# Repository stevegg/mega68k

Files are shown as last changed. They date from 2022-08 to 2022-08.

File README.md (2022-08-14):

# Steve's Mega68k
This project was inspired by others.  It's the unholy union of an Motorola MC68000 CPU and MC68681 DUART with an Arduino Mega along with an AdaFruit SD Card breakout.  This is my attempt to bootstrap building a single board CPU with appropriate software to make it interesting.  My goals are to get the software to a point where it can run both CP/M 68k and a scaled down version of Linux.  

Right now there are 2 software projects:
- Mega68k freerun - implementing a simple freerun mode
- Mega68k simpleLopp - implementing a simple loop and using the arduino as ROM.

Both of these are in the software sub-directory.
The hardware sub-directory contains the KiKad 6.0 project along with the required symbol and footprint libraries and the gerbers.

For Arduino software development I'm using VSCode and the platformio plugin.  This provides a pleasant and smooth development experience.

For assembler I'm using Easy68k...this provides a less smooth and pleasant development experience but it does work and the simulation is quite useful.

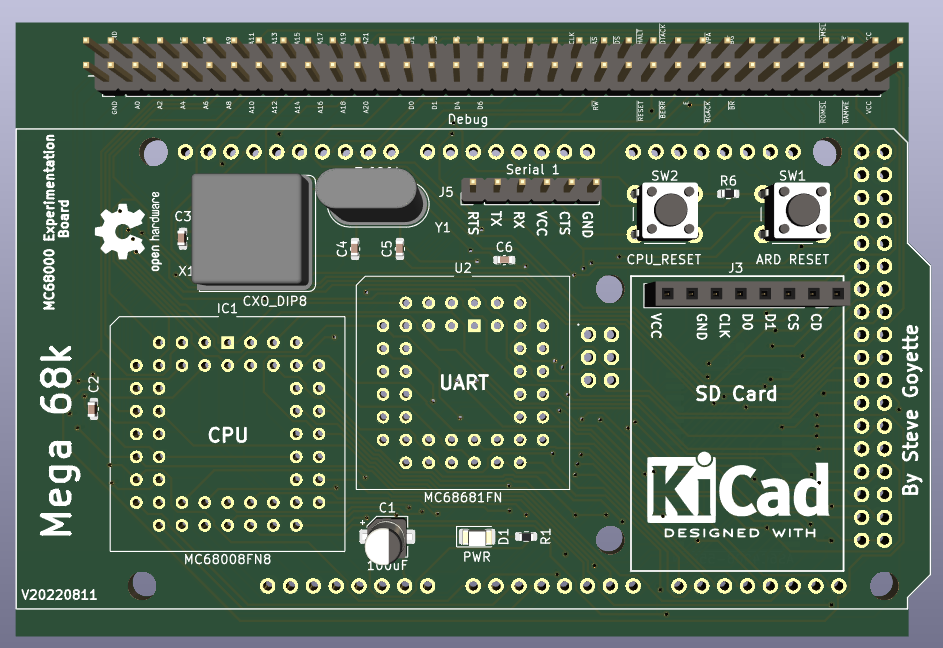
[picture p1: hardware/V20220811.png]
V20220811


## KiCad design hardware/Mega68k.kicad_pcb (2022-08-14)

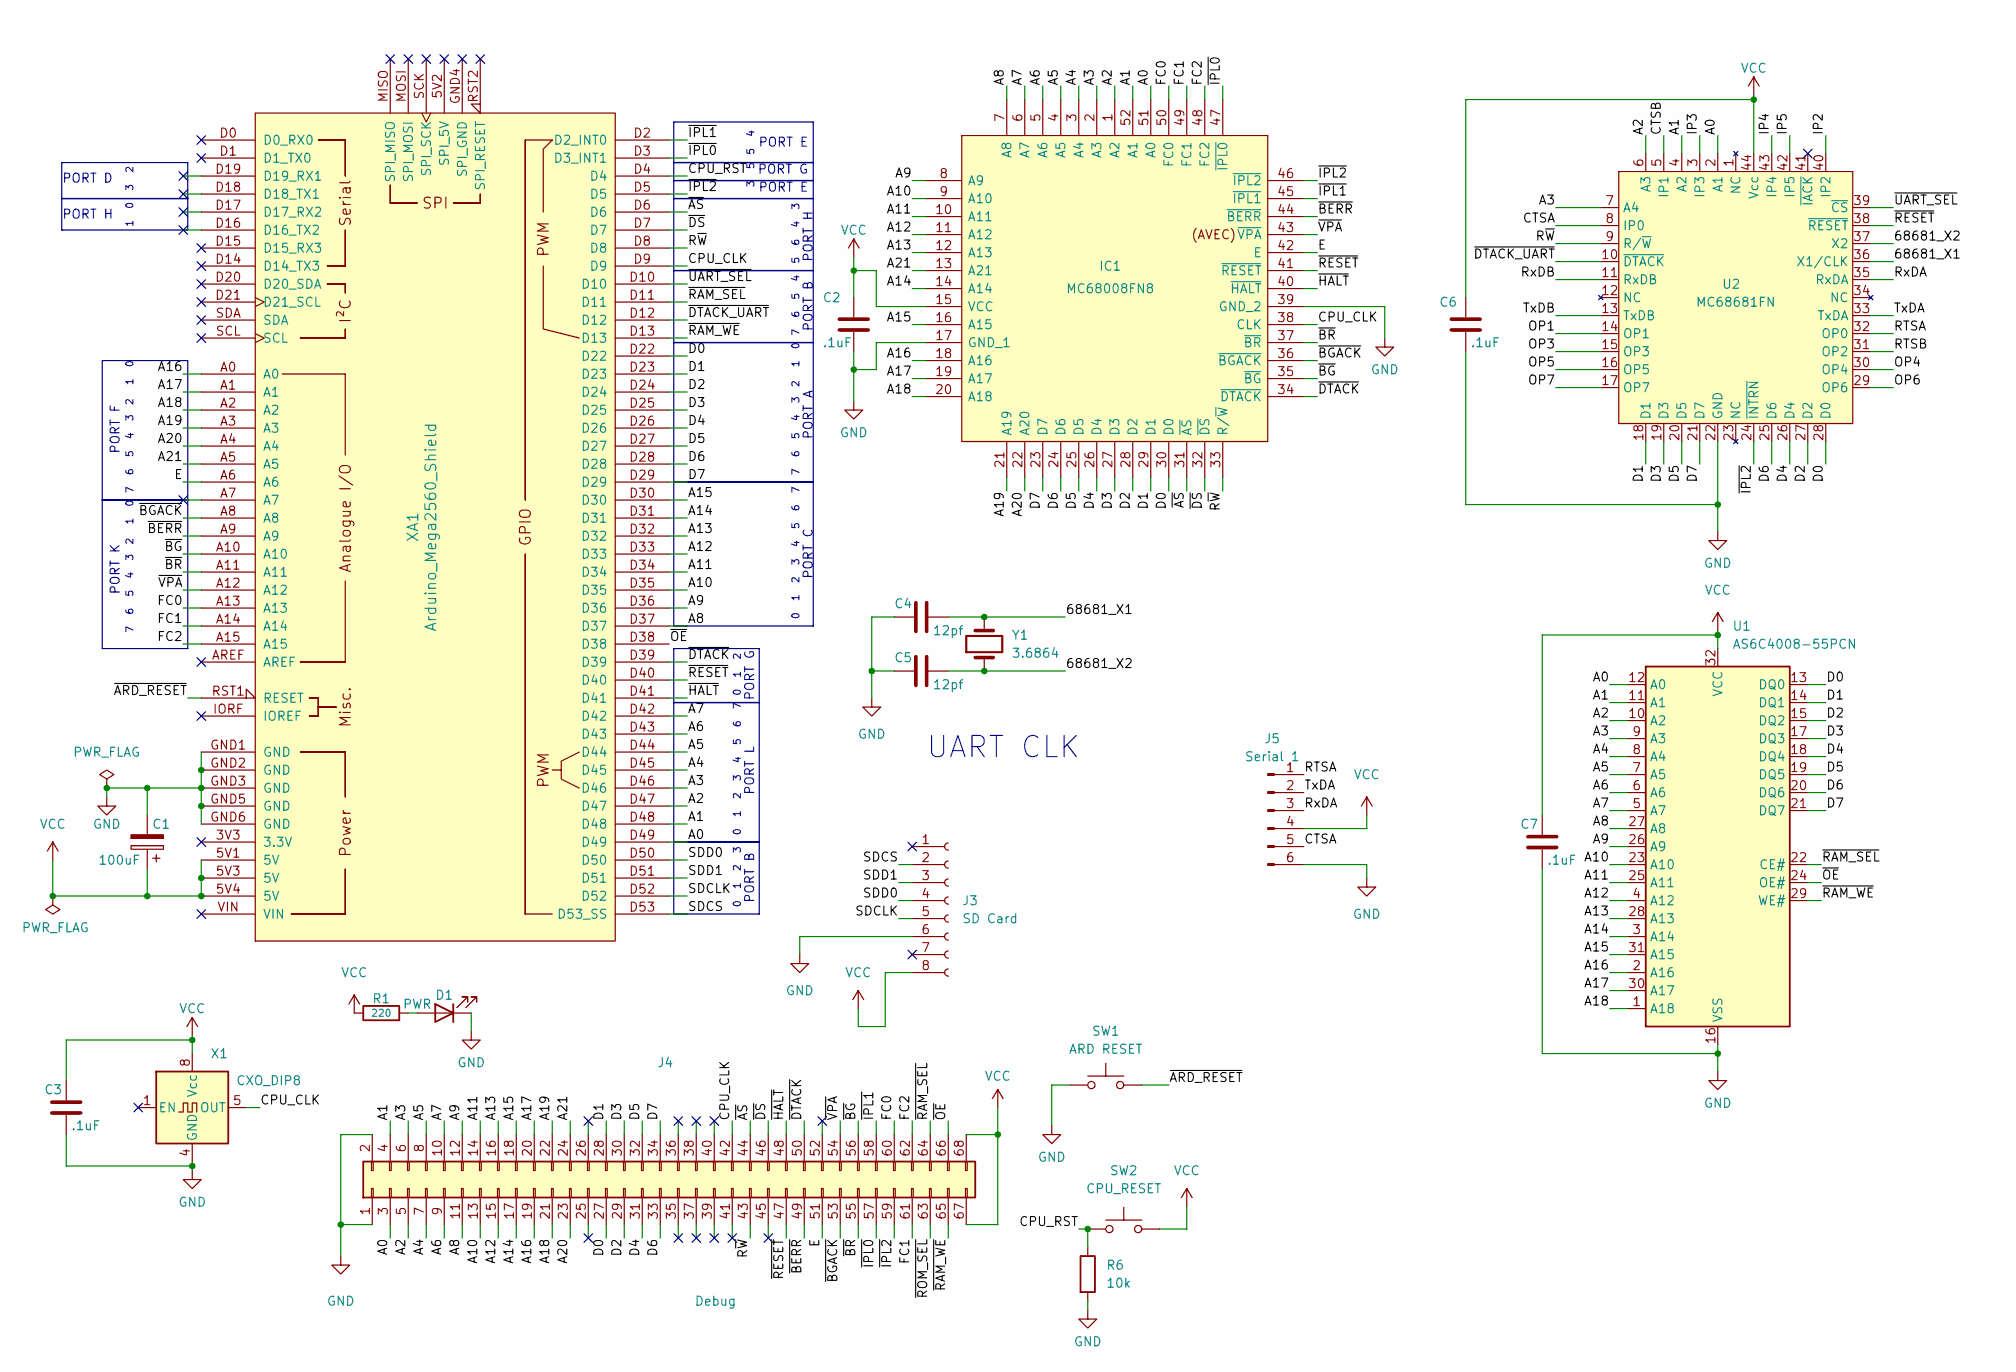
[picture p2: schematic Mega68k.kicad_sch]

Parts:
C1: 100uF; CP_Elec_4x5.4
C2, C3, C6, C7: .1uF; C_0603_1608Metric
C4, C5: 12pf; C_0603_1608Metric
D1: PWR; LED_1206_3216Metric
IC1: MC68008FN8; PLCC-52_THT-Socket; Manufacturer_Part_Number MC68008FN8
J3: SD Card; PinSocket_1x08_P2.54mm_Vertical
J4: Debug; PinHeader_2x34_P2.54mm_Vertical
J5: Serial 1; PinHeader_1x06_P2.54mm_Vertical
R1: 220; R_0603_1608Metric
R6: 10k; R_0603_1608Metric
SW1: ARD RESET; SW_PUSH_6mm
SW2: CPU_RESET; SW_PUSH_6mm
U1: AS6C4008-55PCN; SSOP-32_11.305x20.495mm_P1.27mm
U2: MC68681FN; PLCC-44_THT-Socket
X1: CXO_DIP8; Oscillator_DIP-8
XA1: Arduino_Mega2560_Shield
Y1: 3.6864; Crystal_HC49-U_Vertical

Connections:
/68681_X1: C4.2, U2.36 (X1/CLK), Y1.2
/68681_X2: C5.2, U2.37 (X2), Y1.1
/A0: IC1.51 (A0), J4.3, U1.12 (A0), U2.2 (A1), XA1.D49
/A1: IC1.52 (A1), J4.4, U1.11 (A1), U2.4 (A2), XA1.D48
/A2: IC1.1 (A2), J4.5, U1.10 (A2), U2.6 (A3), XA1.D47
/A3: IC1.2 (A3), J4.6, U1.9 (A3), U2.7 (A4), XA1.D46
/A4: IC1.3 (A4), J4.7, U1.8 (A4), XA1.D45
/A5: IC1.4 (A5), J4.8, U1.7 (A5), XA1.D44
/A6: IC1.5 (A6), J4.9, U1.6 (A6), XA1.D43
/A7: IC1.6 (A7), J4.10, U1.5 (A7), XA1.D42
/A8: IC1.7 (A8), J4.11, U1.27 (A8), XA1.D37
/A9: IC1.8 (A9), J4.12, U1.26 (A9), XA1.D36
/A10: IC1.9 (A10), J4.13, U1.23 (A10), XA1.D35
/A11: IC1.10 (A11), J4.14, U1.25 (A11), XA1.D34
/A12: IC1.11 (A12), J4.15, U1.4 (A12), XA1.D33
/A13: IC1.12 (A13), J4.16, U1.28 (A13), XA1.D32
/A14: IC1.14 (A14), J4.17, U1.3 (A14), XA1.D31
/A15: IC1.16 (A15), J4.18, U1.31 (A15), XA1.D30
/A16: IC1.18 (A16), J4.19, U1.2 (A16), XA1.A0
/A17: IC1.19 (A17), J4.20, U1.30 (A17), XA1.A1
/A18: IC1.20 (A18), J4.21, U1.1 (A18), XA1.A2
/A19: IC1.21 (A19), J4.22, XA1.A3
/A20: IC1.22 (A20), J4.23, XA1.A4
/A21: IC1.13 (A21), J4.24, XA1.A5
/CPU_CLK: IC1.38 (CLK), J4.42, X1.5 (OUT), XA1.D9
/CPU_RST: R6.1, SW2.1, XA1.D4
/CTSA: J5.5, U2.8 (IP0)
/CTSB: U2.5 (IP1)
/D0: IC1.30 (D0), J4.27, U1.13 (DQ0), U2.28 (D0), XA1.D22
/D1: IC1.29 (D1), J4.28, U1.14 (DQ1), U2.18 (D1), XA1.D23
/D2: IC1.28 (D2), J4.29, U1.15 (DQ2), U2.27 (D2), XA1.D24
/D3: IC1.27 (D3), J4.30, U1.17 (DQ3), U2.19 (D3), XA1.D25
/D4: IC1.26 (D4), J4.31, U1.18 (DQ4), U2.26 (D4), XA1.D26
/D5: IC1.25 (D5), J4.32, U1.19 (DQ5), U2.20 (D5), XA1.D27
/D6: IC1.24 (D6), J4.33, U1.20 (DQ6), U2.25 (D6), XA1.D28
/D7: IC1.23 (D7), J4.34, U1.21 (DQ7), U2.21 (D7), XA1.D29
/E: IC1.42 (E), J4.51, XA1.A6
/FC0: IC1.50 (FC0), J4.60, XA1.A13
/FC1: IC1.49 (FC1), J4.61, XA1.A14
/FC2: IC1.48 (FC2), J4.62, XA1.A15
/IP2: U2.40 (IP2)
/IP3: U2.3 (IP3)
/IP4: U2.43 (IP4)
/IP5: U2.42 (IP5)
/OP1: U2.14 (OP1)
/OP3: U2.15 (OP3)
/OP4: U2.30 (OP4)
/OP5: U2.16 (OP5)
/OP6: U2.29 (OP6)
/OP7: U2.17 (OP7)
/RTSA: J5.1, U2.32 (OP0)
/RTSB: U2.31 (OP2)
/RxDA: J5.3, U2.35 (RxDA)
/RxDB: U2.11 (RxDB)
/R~W: IC1.33 (R/~W), J4.43, U2.9 (R/~W), XA1.D8
/SDCLK: J3.5, XA1.D52
/SDCS: J3.2, XA1.D53 (D53_SS)
/SDD0: J3.4, XA1.D50
/SDD1: J3.3, XA1.D51
/TxDA: J5.2, U2.33 (TxDA)
/TxDB: U2.13 (TxDB)
/~ARD_RESET: SW1.2, XA1.RST1 (RESET)
/~AS: IC1.31 (~AS), J4.44, XA1.D6
/~BERR: IC1.44 (~BERR), J4.49, XA1.A9
/~BGACK: IC1.36 (~BGACK), J4.53, XA1.A8
/~BG: IC1.35 (~BG), J4.56, XA1.A10
/~BR: IC1.37 (~BR), J4.55, XA1.A11
/~DS: IC1.32 (~DS), J4.46, XA1.D7
/~DTACK_UART: U2.10 (~DTACK), XA1.D12
/~DTACK: IC1.34 (~DTACK), J4.50, XA1.D39
/~HALT: IC1.40 (~HALT), J4.48, XA1.D41
/~IPL0: IC1.47 (~IPL0), J4.57, XA1.D3 (D3_INT1)
/~IPL1: IC1.45 (~IPL1), J4.58, XA1.D2 (D2_INT0)
/~IPL2: IC1.46 (~IPL2), J4.59, U2.24 (~INTRN), XA1.D5
/~OE: J4.66, U1.24 (OE#), XA1.D38
/~RAM_SEL: J4.64, U1.22 (CE#), XA1.D11
/~RAM_WE: J4.65, U1.29 (WE#), XA1.D13
/~RESET: IC1.41 (~RESET), J4.47, U2.38 (~RESET), XA1.D40
/~ROM_SEL: J4.63
/~UART_SEL: U2.39 (~CS), XA1.D10
/~VPA: IC1.43 (~VPA), J4.54, XA1.A12
GND: C1.2, C2.2, C3.2, C4.1, C5.1, C6.2, C7.2, D1.1 (K), IC1.17 (GND_1), IC1.39 (GND_2), J3.6, J4.1, J4.2, J5.6, R6.2, SW1.1, U1.16 (VSS), U2.22 (GND), X1.4 (GND), XA1.GND1 (GND), XA1.GND2 (GND), XA1.GND3 (GND), XA1.GND5 (GND), XA1.GND6 (GND)
unnamed: D1.2 (A), R1.2
VCC: C1.1, C2.1, C3.1, C6.1, C7.1, IC1.15 (VCC), J3.8, J4.67, J4.68, J5.4, R1.1, SW2.2, U1.32 (VCC), U2.44 (Vcc), X1.8 (Vcc), XA1.5V1 (5V), XA1.5V3 (5V), XA1.5V4 (5V)

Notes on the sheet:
PORT H
PORT A
UART CLK
PORT E
PORT B
PORT D
PORT C
PORT G
PORT K
PORT F
PORT L

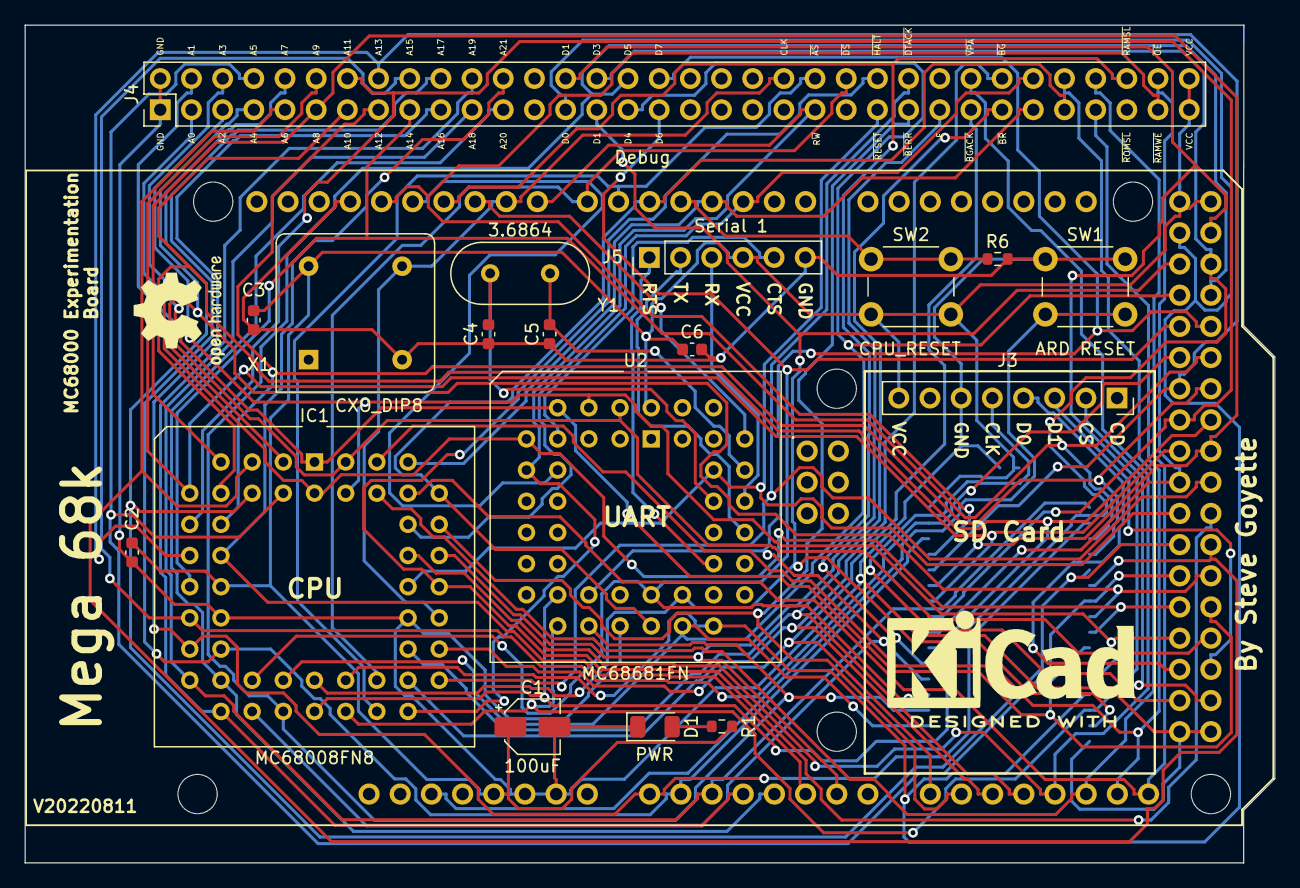
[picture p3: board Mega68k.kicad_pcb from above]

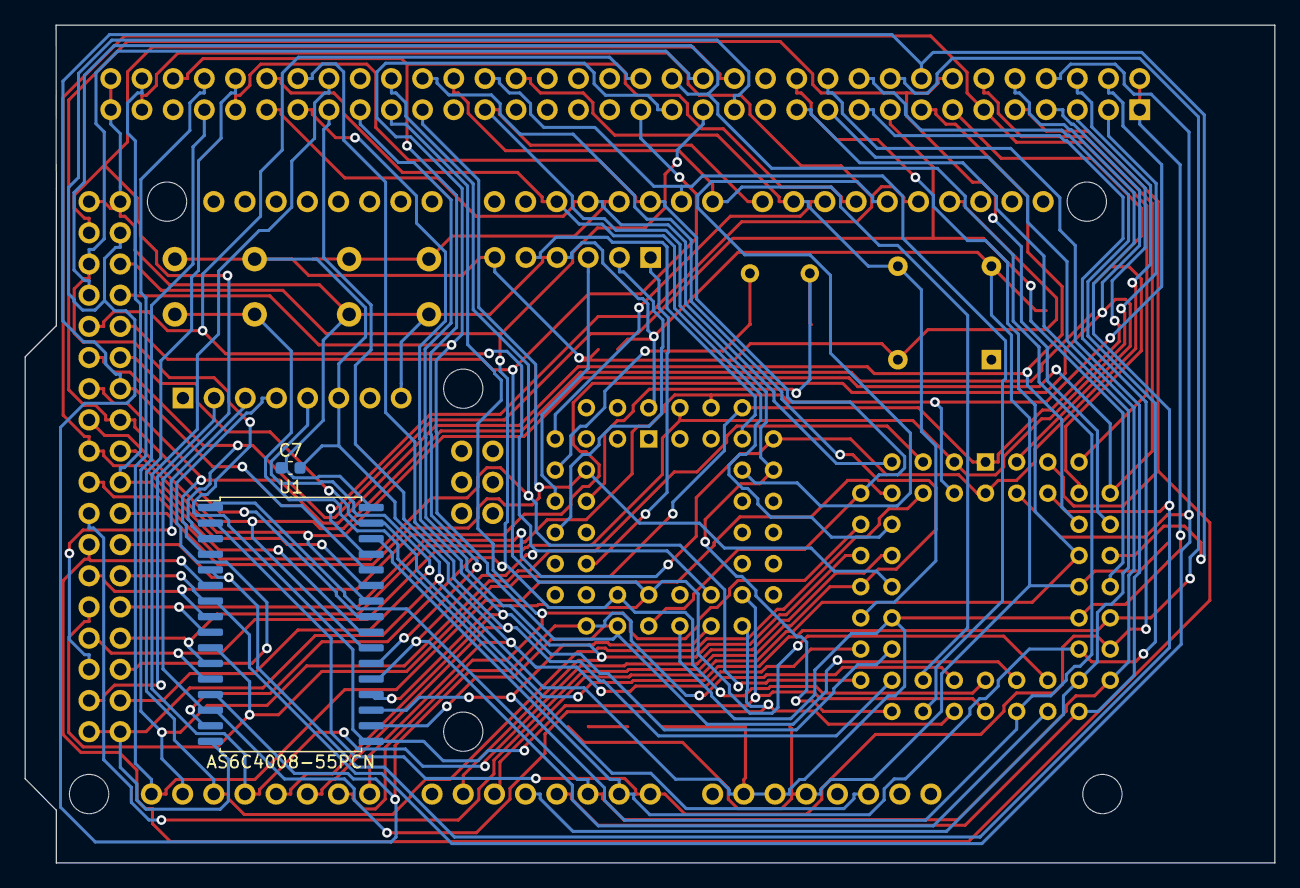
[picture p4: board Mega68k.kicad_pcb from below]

Board: 2 copper layers, 101.8 x 68.2 mm, 23 parts (2 on the bottom side), 69 nets.

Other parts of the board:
Logo1: KiCad-Logo2_8mm_SilkScreen
Logo2: OSHW-Logo2_9.8x8mm_SilkScreen

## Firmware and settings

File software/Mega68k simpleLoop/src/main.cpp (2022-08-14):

#include <Arduino.h>
#include "defines.h"
#include "utils.h"

char buffer[128];

byte simpleLoop[] = {
  0x00, 0x00, 0x00, 0xD2, 0x00, 0x00, 0x00, 0xc0, 0x00, 0x00, 0x00, 0xD0, 0x00, 0x00, 0x00, 0xD0,
  0x00, 0x00, 0x00, 0xD0, 0x00, 0x00, 0x00, 0xD0, 0x00, 0x00, 0x00, 0xD0, 0x00, 0x00, 0x00, 0xD0,
  0x00, 0x00, 0x00, 0xD0, 0x00, 0x00, 0x00, 0xD0, 0x00, 0x00, 0x00, 0xD0, 0x00, 0x00, 0x00, 0xD0,
  0x00, 0x00, 0x00, 0xD0, 0x00, 0x00, 0x00, 0xD0, 0x00, 0x00, 0x00, 0xD0, 0x00, 0x00, 0x00, 0xD0,
  0x00, 0x00, 0x00, 0xD0, 0x00, 0x00, 0x00, 0xD0, 0x00, 0x00, 0x00, 0xD0, 0x00, 0x00, 0x00, 0xD0,
  0x00, 0x00, 0x00, 0xD0, 0x00, 0x00, 0x00, 0xD0, 0x00, 0x00, 0x00, 0xD0, 0x00, 0x00, 0x00, 0xD0,
  0x00, 0x00, 0x00, 0xD0, 0x00, 0x00, 0x00, 0xD0, 0x00, 0x00, 0x00, 0xD0, 0x00, 0x00, 0x00, 0xD0,
  0x00, 0x00, 0x00, 0xD0, 0x00, 0x00, 0x00, 0xD0, 0x00, 0x00, 0x00, 0xD0, 0x00, 0x00, 0x00, 0xD0,
  0x00, 0x00, 0x00, 0xD0, 0x00, 0x00, 0x00, 0xD0, 0x00, 0x00, 0x00, 0xD0, 0x00, 0x00, 0x00, 0xD0,
  0x00, 0x00, 0x00, 0xD0, 0x00, 0x00, 0x00, 0xD0, 0x00, 0x00, 0x00, 0xD0, 0x00, 0x00, 0x00, 0xD0,
  0x00, 0x00, 0x00, 0xD0, 0x00, 0x00, 0x00, 0xD0, 0x00, 0x00, 0x00, 0xD0, 0x00, 0x00, 0x00, 0xD0,
  0x00, 0x00, 0x00, 0xD0, 0x00, 0x00, 0x00, 0xD0, 0x00, 0x00, 0x00, 0xD0, 0x00, 0x00, 0x00, 0xD0,
  0x10, 0x3c, 0x00, 0x00, 0xb0, 0x3c, 0x00, 0xff, 0x67, 0xf6, 0x52, 0x40, 0x4e, 0xf8, 0x00, 0xc4,
  0x4e, 0x73 };

// MC68000 is Big Endian so we need to return
// a WORD consisting of HI Byte then LO Byte
word getROM(unsigned long address) {
  return ((simpleLoop[address] << 8) | simpleLoop[address+1]);
}

void resetCPU() {
  Serial.println("Reset CPU");

  // Set HALT to an output
  DDRG |= (1<<HALT_PIN);

  // Bring both RESET and HALT pins low
  PORTG &= ~((1<<RESET_PIN) | (1<<HALT_PIN));
    // Make sure we delay at least 20x00ms
  delay(10);
  // Now set reset and HALT to HIGH
  PORTG |= ((1<<RESET_PIN) | (1<<HALT_PIN));

  // Set HALT to an input
  DDRG &= ~(1<<HALT_PIN);
}

// PORT MANIPULATION
// To set bits use PORT
// To read bits use PIN
// Set DDR Bits to 1 for OUTPUT, 0 for INPUT

void setup() {

  // Setup Serial port
  Serial.begin(9600);
  Serial.println("Initializing");

  // Set DTACK, RESET and HALT Pin as OUTPUT
  DDRG |= (
    (1<<DTACK_PIN) |
    (1<<RESET_PIN)
  );
  // Set HALT to INPUT
  DDRG &= ~(1<<HALT_PIN);

  // Set DTACK, RESET and HALT all hi
  PORTG |= ((1<<DTACK_PIN) | (1<<RESET_PIN) | (1<<HALT_PIN));

  // Set BERR, VPA and BGACK pins to output
  DDRK |= (
    (1<<VPA_PIN) |
    (1<<BERR_PIN) |
    (1<<BGACK_PIN) |
    (1<<BR_PIN)
  );

  // Set BERR, VPA and BGACK and BR hi
  PORTK |= ((1<<BERR_PIN) | (1<<VPA_PIN) | (1<<BGACK_PIN) | (1<<BR_PIN));

  // Set IPL0, IPL1 and IPL2 pins to output
  DDRE |= (
    (1<<IPL0_PIN) |
    (1<<IPL1_PIN) |
    (1<<IPL2_PIN)
  );
  // Set IPL0, IPL1 and IPL2 all hi
  PORTE |= ((1<<IPL0_PIN) | (1<<IPL1_PIN) | (1<<IPL2_PIN));

  // Set R/W, FC0, FC1 and FC2 pins to input
  DDRH = DDRH & ~((1<<RW_PIN) | (1<<FC0_PIN) | (1<<FC1_PIN) | (1<<FC2_PIN));

  // Setup address as input
  ADDRESS_LOW_DDR = 0x00;
  ADDRESS_HI_DDR = 0x00;
  ADDRESS_X_DDR = 0x00;

  // Data bus as output (may also be input)
  DATA_LOW_DDR = B11111111;
  DATA_HI_DDR = B11111111;

  // Set everything to zero
  DATA_LOW_PORT = 0x00;
  DATA_HI_PORT = 0x00;

  // Set CLK_INPUT pin to INPUT
  DDRG &= ~(1<<CLK_INPUT);

  // Set AS as INPUT
  DDRD &= ~(1<<ADDRESS_STROBE_PIN);

  resetCPU();
  Serial.println("Init complete. Type a command, ? for help");
}



void loop() {

  // Check for Address Strobe
  if ( !(PIND & (1<<ADDRESS_STROBE_PIN)) ) {
    // Check R/W state
    boolean reading = (PINH & (1<<READ_WRITE_PIN));
    // Get the address
    unsigned long address = getAddress();

    word data = getROM(address);
    setDataBus(data);

    sprintf(buffer, "%c 0x%06lX : 0x%04X", 
      (reading)?'R':'W',
      address, 
      data);
    Serial.println(buffer);
    Serial.print("Ready >");
    while ( !Serial.available() );
    char c = Serial.read();
    Serial.println(c);
    if ( c == 'n' || c == 'N' ) {
      // Assert DTACK
      PORTG &= ~(1 << DTACK_PORT);
      delayMicroseconds(2);
      // UnAssert DTACK
      PORTG |= (1 << DTACK_PORT);
    } else if ( c == 'g' || c == 'G' ) {
      // Assert DTACK and leave it
      PORTG &= ~(1 << DTACK_PORT);
    } else if ( c == 'r' || c == 'R' ) {
      resetCPU();
    } else if ( c == '?') {
      Serial.println("Steve's Mega68k Monitor");
      Serial.println("-----------------------\n");
      Serial.println("g/G - Go");
      Serial.println("n/N - Next Instruction");
      Serial.println("r/R - Reset 68k CPU");
      Serial.println("?   - This help");
      Serial.println();
    } else {
      Serial.println("Syntax Error");
    }
  }
}

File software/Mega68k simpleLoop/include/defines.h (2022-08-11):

#ifndef __DEFINES_H
#define __DEFINES_H

#include <Arduino.h>

// Low byte of address bus
#define ADDRESS_LOW_PIN     PINL
#define ADDRESS_LOW_PORT    PORTL
#define ADDRESS_LOW_DDR     DDRL

// Hi byte of address bus
#define ADDRESS_HI_PIN      PINC
#define ADDRESS_HI_PORT     PORTC
#define ADDRESS_HI_DDR      DDRC

// Extra byte of address bus
#define ADDRESS_X_PIN       PINB
#define ADDRESS_X_PORT      PORTB
#define ADDRESS_X_DDR       DDRB

// Low byte of data bus
#define DATA_LOW_PIN        PINA
#define DATA_LOW_PORT       PORTA
#define DATA_LOW_DDR        DDRA

// Hi byte of data bus
#define DATA_HI_PIN         PINF
#define DATA_HI_PORT        PORTF
#define DATA_HI_DDR         DDRF

#define ADDRESS_STROBE_PIN  PORTD1
#define READ_WRITE          7
#define READ_WRITE_PIN      PORTH4

#define DTACK_PORT          PORTG2
#define DTACK_PIN           PING2
#define RESET_PORT          PORTG1
#define RESET_PIN           PING1
#define HALT_PORT           PORTG0
#define HALT_PIN            PING0

#define RW_PIN              PORTH4
#define CLK_INPUT           PORTG5

#define VPA_PIN             PORTK4
#define BERR_PIN            PORTK1
#define BGACK_PIN           PORTK0
#define BR_PIN              PORTK3

#define IPL0_PIN            PORTE5
#define IPL1_PIN            PORTE4
#define IPL2_PIN            PORTE3

#define FC0_PIN             PORTH0
#define FC1_PIN             PORTH1
#define FC2_PIN             PORTH3

#define CHECK_BIT(var,pos) ((var) & (1<<(pos)))

#define IsReading()         (PORTH & (1<<PORTH4)) > 0

#endif

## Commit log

2022-07-21 Initial commit of V220718
    [Mega68k-B_Cu.gbr, Mega68k-B_Mask.gbr, Mega68k-B_Paste.gbr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]
2022-08-04 Fixed 64 pin socket size and added more status lights
    [Mega68k.kicad_pcb, Mega68k.kicad_sch]
2022-08-04 Updated version label
    [Mega68k.kicad_pcb]
2022-08-06 Updated with trace routing
    [Mega68k.kicad_pcb]
2022-08-06 Added an arduino reset switch
    [Mega68k.kicad_pcb, Mega68k.kicad_sch]
2022-08-06 Added freerun software sketch for platformio
    [Mega68k.kicad_pcb, Mega68k.kicad_sch]
2022-08-11 Working freerun
    [Mega68k.kicad_pcb, Mega68k.kicad_sch]
2022-08-12 More tweaks to schematics before next rev V20220811
    [Mega68k.kicad_pcb, Mega68k.kicad_sch]
2022-08-12 Added simple loop code and finalized board
    [Mega68k.kicad_pcb]
2022-08-14 Added program to do simple loop testing ROM access
    [Mega68k-B_Cu.gbr, Mega68k-B_Mask.gbr, Mega68k-B_Paste.gbr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]
2022-08-14 Some Reorganization
    [Mega68k-B_Cu.gbr, Mega68k-B_Mask.gbr, Mega68k-B_Paste.gbr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]
2022-08-14 Some cleanup
    [Mega68k.kicad_pcb, Mega68k.kicad_sch]
2022-08-14 Added PCB image for V20220811
